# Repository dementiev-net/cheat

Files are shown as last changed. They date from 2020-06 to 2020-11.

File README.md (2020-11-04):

Электронная шпаргалка от AlexGyver
=====================

Это электронная шпаргалка, позволяющая незаметно списать тест. Авторский проект [AlexGyver](https://alexgyver.ru/gyvercheat/) разведенный на одной маленькой плате. Так же используется небольшой LiPo аккумулятор с возможностью зарядки. В остальном по функциональности ничем не отличается от версии на Arduino Nano.

| Сторона 1 | Сторона 2
|---|---
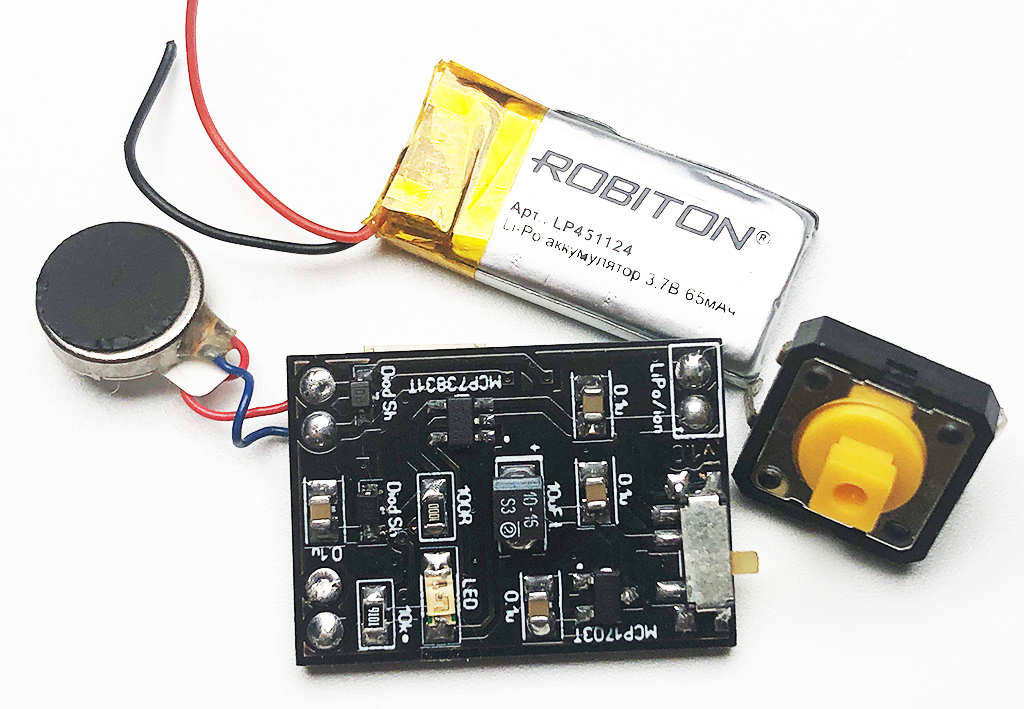
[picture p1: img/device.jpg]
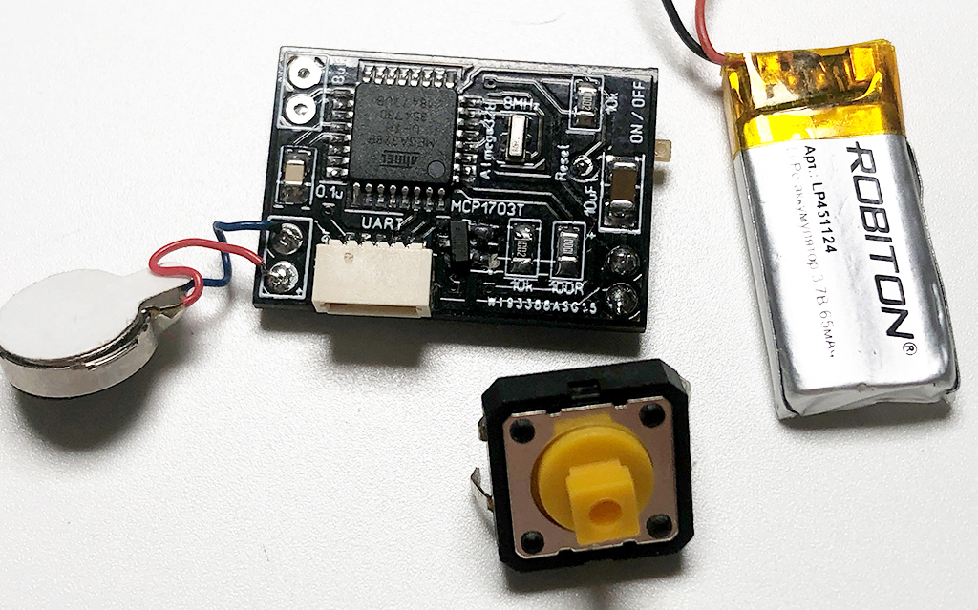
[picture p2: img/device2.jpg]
|  | 

Особенности:

*	Хранение ответов в EEPROM памяти микроконтроллера (до 1020 цифр);
*	Управление одной кнопкой;
*	Вывод ответов количеством вибраций;
*   Добавление билетов по UART;

## Инструкция по эксплуатации

Подключаем по UART к компьютеру и заносить билеты с ответами на них. Как это делается подробно рассказывает автор в своем [видео](https://www.youtube.com/watch?v=9YlfDXCbW8]).

Накликиваем нужный билет/вариант – получаем подтверждение в виде количества импульсов вибрации.

**Долгий клик** – выбор билета/варианта, подтверждение – одиночный короткий импульс вибрации. Пока билет не выбран долгим кликом, можно накликать другой номер!

**Клик** – вывод вибрацией ответа на следующий вопрос.

**Долгий клик** – возврат в меню, подтверждение – долгая вибрация. Долгая вибрация также будет при ошибках (нет такого билета, закончились вопросы в выбранном билете).

## Распиновка разъема

5-и контактный разъем JST-SH 1.0 мм. служит для подключение к USB через USB-UART конвертер а также зарядки аккумулятора. О зарядке информирует светодиод. Когда он погаснет - зарядка окончена.

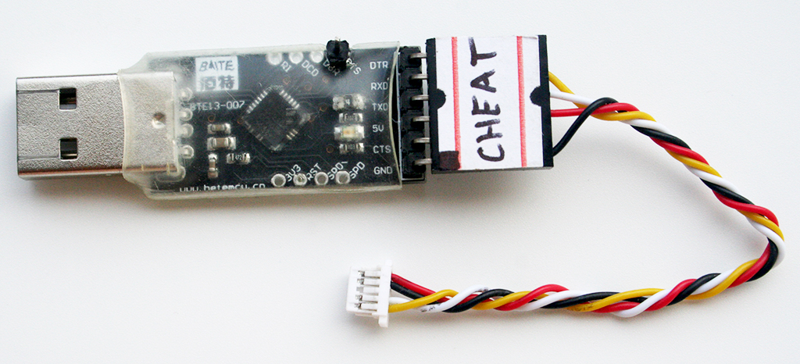
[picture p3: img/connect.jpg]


|  USB-UART конвертер | Разъем платы
|---|---
|1. DTR -|1. 5V - Красный провод
|2. RX - Желтый провод|2. GND - Черный провод
|3. TX - Белый провод|3. -
|4. 5V - Красный провод (нужен для зарядки аккумулятора)|4. RX - Белый провод
|5. CTS -|5. TX - Желтый провод
|6. GND - Черный провод (нужен для зарядки аккумулятора)|

## Схемы

Оригинальная схема автора. Используется Arduino Nano и плата контроллера заряда аккумулятора TP4056.

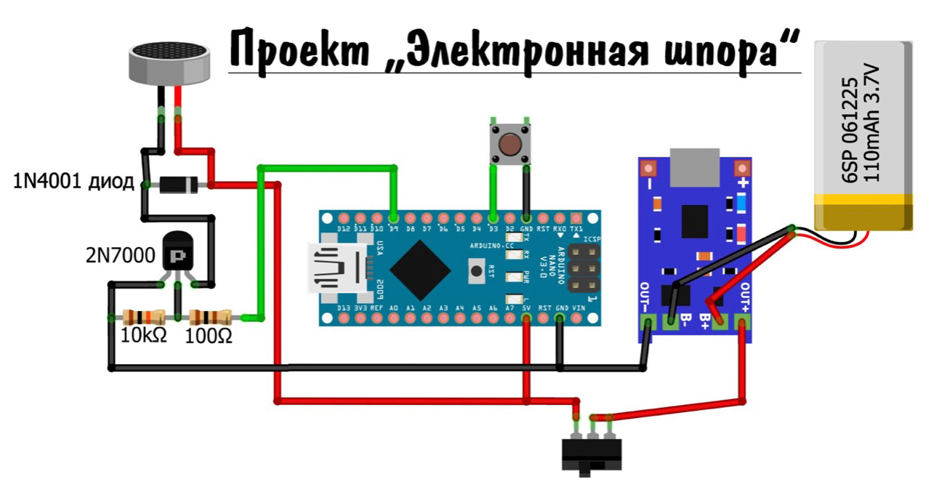
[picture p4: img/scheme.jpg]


В схему добавлено:

|MCP73831T-2ACI/OT<br>Контроллер заряда батарей Li-Ion/Li-Pol 15mA to 500mA 4.2V [SOT-23-5]| MCP1703T-3302E/CB<br>Регулятор напряжения линейный, 200MA 3.3V [SOT-23A]
|---|---
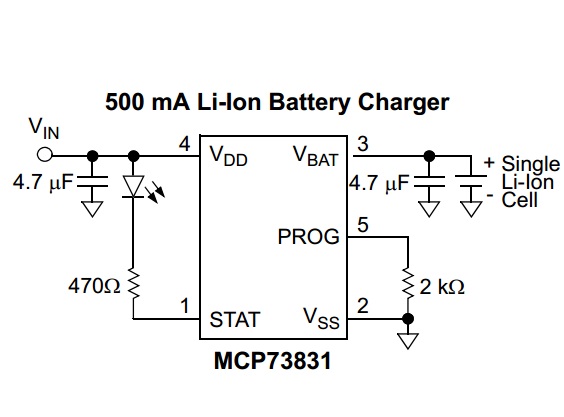
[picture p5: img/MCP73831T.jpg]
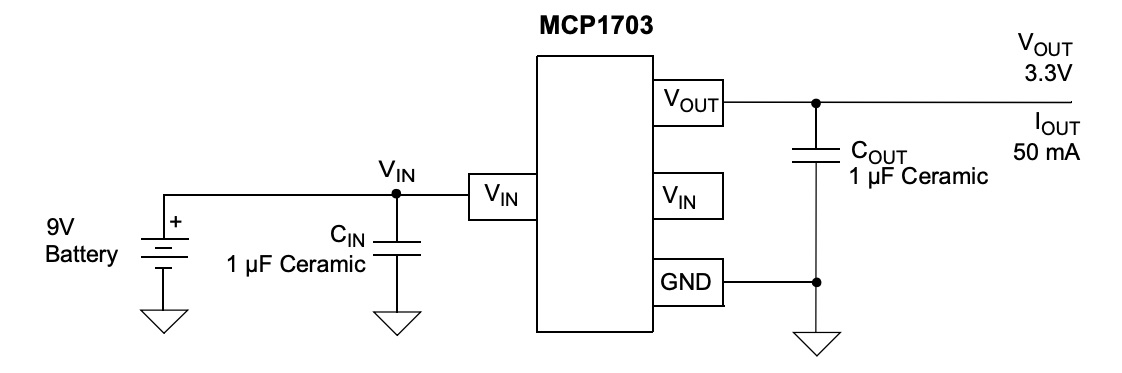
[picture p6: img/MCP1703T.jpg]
|  | 

## Плата

Делалась как можно компактнее, но пригодная к повторению.

| Верх | Низ
|---|---
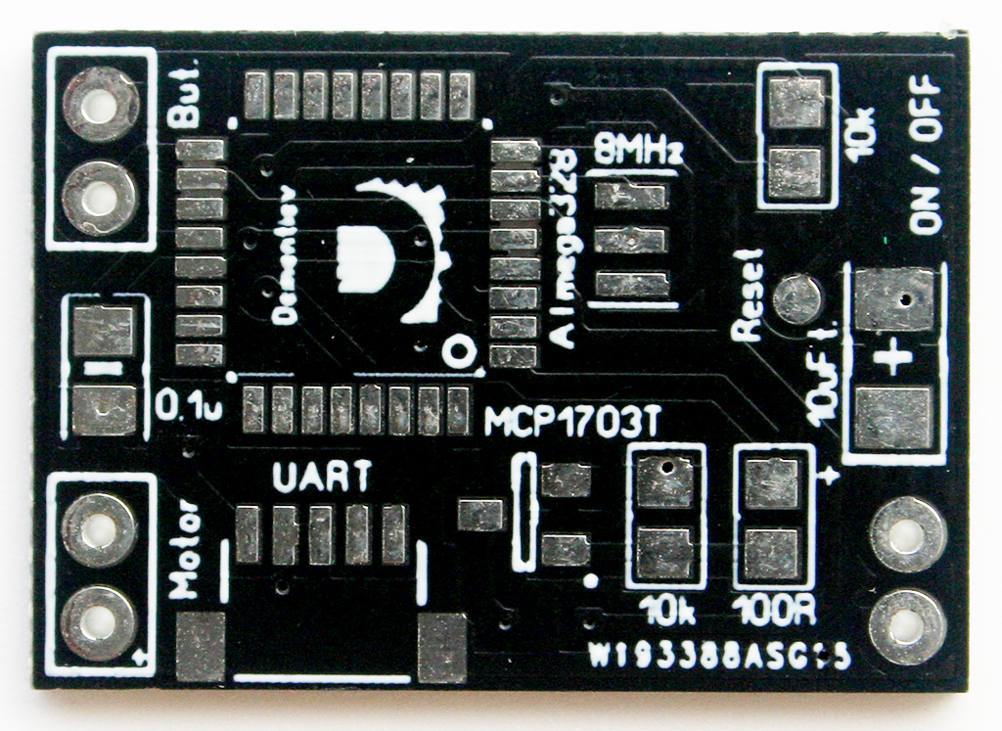
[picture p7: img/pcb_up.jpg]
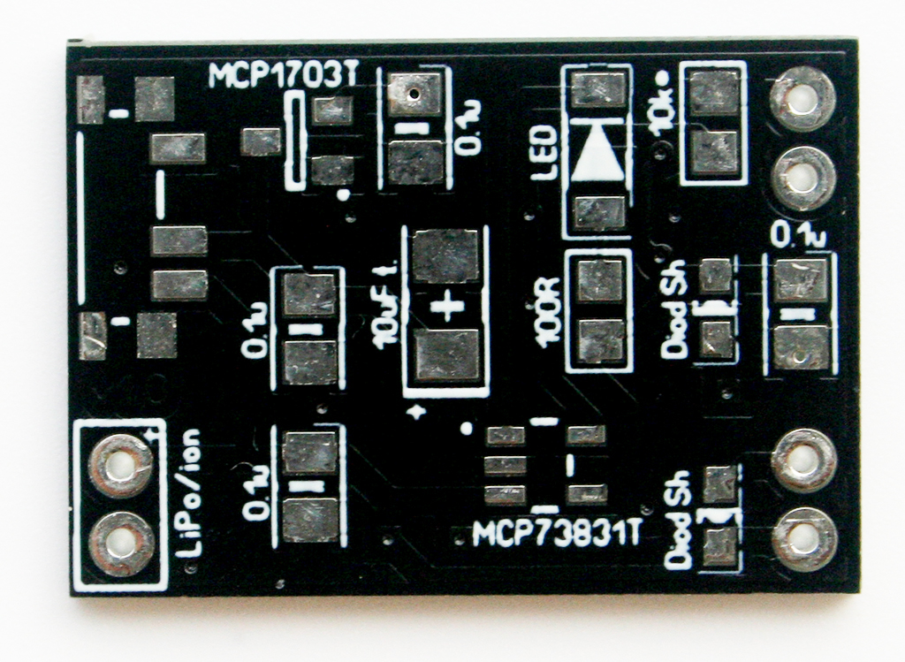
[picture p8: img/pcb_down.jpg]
|  | 

#### BOM:

|No|Name|Value|Layer|Comment
|---|---|---|---|---
|1|C1,C2|10u|Top,Bottom|Tantal
|2|C3,C4,C5,C6,C7|0.1u|Top,Bottom|0805
|3|D1,D2|BAT20|Bottom|SOD-323
|4|D3||Bottom|LED
|5|J1|SM05B-SRSS-TB|Top|
|6|J2|MK12C02|Bottom|
|7|Q1|8Mhz|Top|
|8|Q2|IRFML8244|Top|SOT-23A
|9|R1,R2,R3|10k|Top,Bottom|0805
|10|R4,R5|100R|Top,Bottom|0805
|11|U1|Atmega328|Top|TQFP-32
|12|U2|MCP73831T|Bottom|SOT-23-5
|13|U3|MCP1703T|Bottom|SOT-23A

## Корпус

Корпус распечатан на 3D принтере. Предназначен для удобной сборки в один небольшой корпус. Используется разъем JST PH 2.0 мм. 2-Pin для выноса кнопки на провод.

| Корпус | Сборка
|---|---
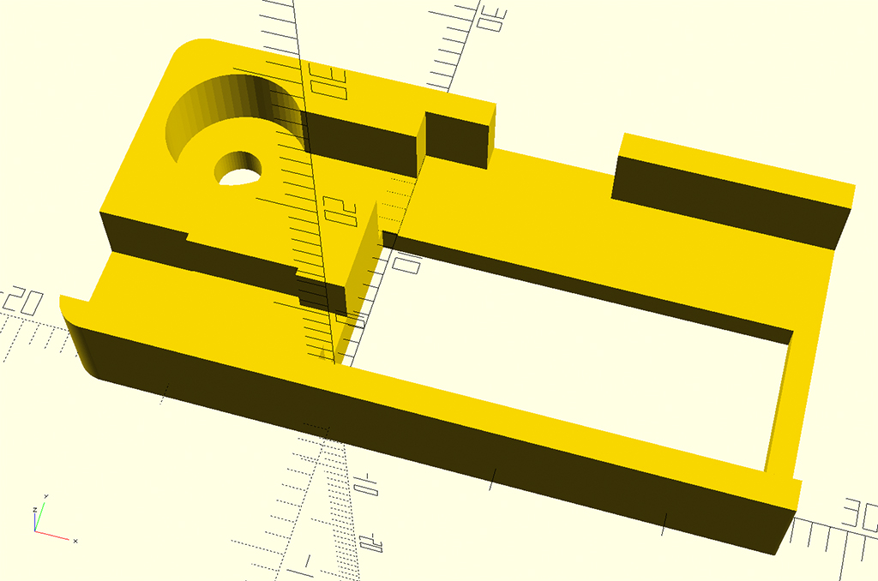
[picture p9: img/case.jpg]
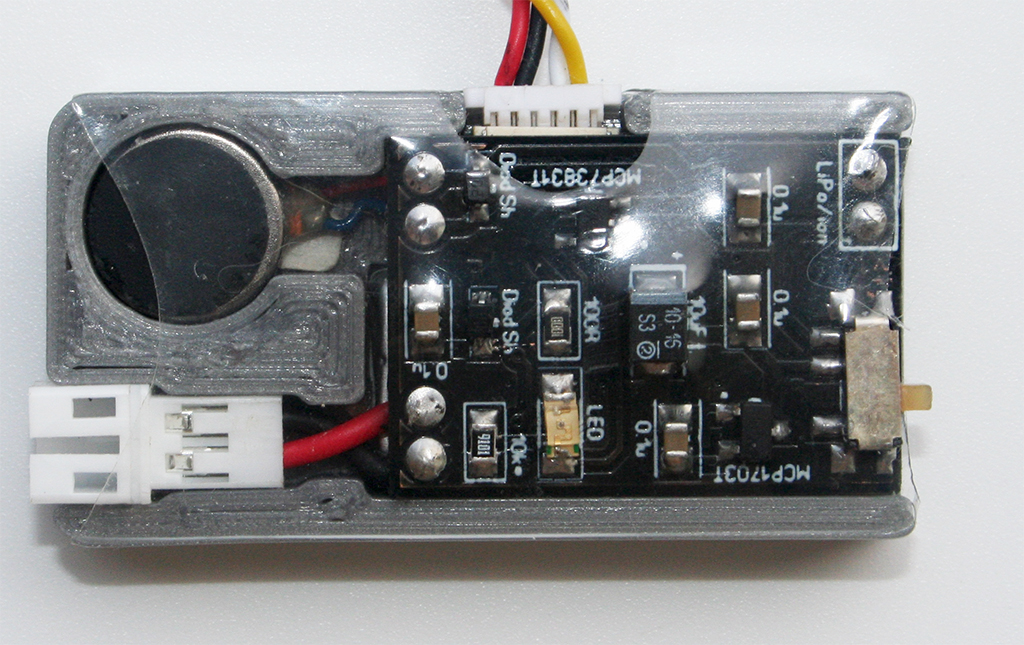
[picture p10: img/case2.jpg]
|  | 

## Прошивка

* Любым программатором загружается bootloader (HEX файл и фьюзы прилагаются). Самой простой вариант прошить через USB Arduino NANO и "сдуть" с нее чип.
* Впаивается чип на плату.
* Заливается INO файл из Arduino IDE (как Arduino NANO) с помощью USB-UART преобразователя (FTDI).

## Контакты

GitHub автора: [https://github.com/AlexGyver/GyverCheat](https://github.com/AlexGyver/GyverCheat)

Связаться со мной: info@dementiev.net

##### Лицензия: «Attribution-NonCommercial-ShareAlike»<br>(«Атрибуция — Некоммерческое использование — На тех же условиях») 4.0 Всемирная



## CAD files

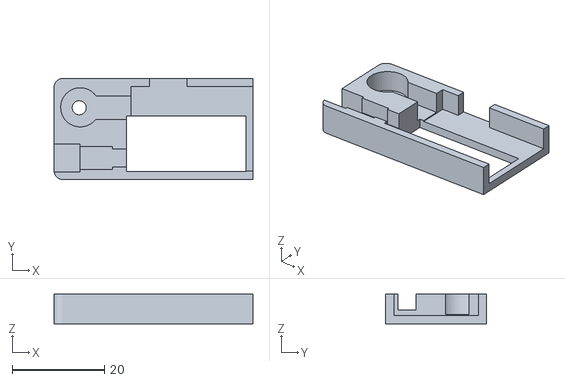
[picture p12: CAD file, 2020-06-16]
3d print/case 8mm motor.stl
43.2 x 22.0 x 6.50

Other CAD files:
3d print/case 10mm motor.stl

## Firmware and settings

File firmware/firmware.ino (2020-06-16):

/*
  Скетч к проекту "Электронная супер-шпора"
  Страница проекта (схемы, описания): https://alexgyver.ru/GyverCheat/
  Исходники на GitHub: https://github.com/AlexGyver/GyverCheat/
  Нравится, как написан код? Поддержи автора! https://alexgyver.ru/support_alex/
  Автор: AlexGyver Technologies, 2018
  https://AlexGyver.ru/

  Версия 1.1 - пофикшен критический баг!
*/

/*
   Накликиваем нужный билет/вариант - получаем подтверждение в виде количества импульсов вибрации
   Долгий клик - выбор билета/варианта, подтверждение - одиночный короткий импульс вибрации 
   Клик - вывод вибрацией ответа на следующий вопрос
   Долгий клик - возврат в меню, подтверждение - долгая вибрация
   Долгая вибрация также будет при ошибках (нет такого билета, закончились вопросы в выбранном билете)
*/

// ----------------- НАСТРОЙКИ -----------------
#define BUF_SIZE 1000	  // размер буфера (0-1021)
#define MODE 1          // 0 - карта памяти, 1 - EEPROM
#define MOTOR_SPEED 250 // скорость мотора (0-255)
#define BTN 13          // пин кнопки
#define MOTOR 3         // пин мотора

// настройки времени вибрации
#define PAUSE 500             // пауза между вибрациями, мс (когда выводит цифру)
#define LONG_VIBR 1500        // длинная вибрация, мс (при ошибках и любом выходе в корень)
#define ANSWER_VIBR 300       // длина импульса при выводе цифры, мс
#define MANY_ANSW_PAUSE 1000  // пауза между ответами, когда в вопросе их несколько, мс

// ----------------- ДЛЯ РАЗРАБОТЧИКОВ -----------------
#define SIZE_POS 1022     // позиция ячейки с размером буфера
#include "GyverButton.h"
GButton butt(BTN);

#if (MODE == 0)
#include <SPI.h>
#include <SD.h>
File myFile;
const char *filename;
#define logName "exam.txt"
#else
#include "EEPROMex.h"
#endif

char buf[BUF_SIZE];
uint16_t bufSize;
uint16_t bufPos;
uint16_t bufCounter;

void setup() {
  Serial.begin(9600);
  butt.setTimeout(800);
#if (MODE == 0)
  Serial.print(F("Initializing SD card..."));
  if (!SD.begin(10)) {
    Serial.println(F(" failed!"));
  }
  Serial.println(F(" done"));

  if (SD.exists(logName)) {
    Serial.print(logName); Serial.println(F(" found"));
  } else {
    Serial.print(logName); Serial.println(F(" not found"));
  }

  myFile = SD.open(logName, FILE_READ);

  int fileSize = myFile.size();
  bufPos = 0;
  bufCounter = 0;
  myFile.seek(0);
  for (int i = 0; i < fileSize; i++) {
    char sdBuf = (char)myFile.read();
    if (sdBuf > 38 && sdBuf < 122) {
      buf[bufCounter] = sdBuf;
      bufCounter++;
    }
  }
  bufSize = bufCounter;
#else
  if (EEPROM.read(SIZE_POS) != 255 && EEPROM.read(SIZE_POS + 1) != 255) {
    bufSize = EEPROM.readInt(SIZE_POS);
    for (int i = 0; i < bufSize; i++) {
      buf[i] = (char)EEPROM.readByte(i);
    }
    Serial.println(F("EEPROM read OK"));
  }
#endif
  Serial.println(F("System start"));
  pinMode(MOTOR, OUTPUT);
}

byte ticket = 1;
byte question = 0;
byte answer;
byte mode = 0;
uint16_t ticketPos;

char bufRead() {
#if (MODE == 0)
  char retChar = myFile.read();
#else
  char retChar = buf[bufPos];
#endif
  bufPos++;
  return retChar;
}

void loop() {
  if (Serial.available() > 0) {
    bufCounter = 0;
#if (MODE == 0)
    myFile.seek(0);   // в начало файла
#endif
    uint32_t timeoutTimer = millis();
    while (millis() - timeoutTimer < 500) {
      while (Serial.available() > 0) {
        timeoutTimer = millis();
        char serialBuf = Serial.read();
        if (serialBuf > 38 && serialBuf < 122) {
#if (MODE == 1)
          buf[bufCounter] = serialBuf;
          bufCounter++;
          if (bufCounter > BUF_SIZE) {
            Serial.println(F("Buffer overflow"));
            break;
          }
#else
          bufCounter++;
          myFile.print(serialBuf);
#endif
        }
      }
    }
    Serial.println(F("Serial read success"));
    bufSize = bufCounter;
#if (MODE == 1)
    for (int i = 0; i < bufSize; i++) {
      EEPROM.updateByte(i, (byte)buf[i]);
    }
    EEPROM.updateInt(SIZE_POS, bufSize);
    Serial.println(F("EEPROM write success"));
#else
    myFile.flush();
    Serial.println(F("SD write success"));
#endif
    for (int i = 0; i < bufSize; i++) {
      Serial.print(buf[i]);
    }
  }

  butt.tick();    // опрос кнопки

  if (butt.isHolded()) {
    if (mode == 0) {
      mode = 1;
      Serial.println(F("Ticket chosen"));
      bufPos = 0;
#if (MODE == 0)
      myFile.seek(0);   // в начало файла
#endif
      while (true) {
        if (bufRead() == 'B') {     // ищем префикс B
          char buf1 = bufRead();
          char buf2 = bufRead();
          byte tickNum;
          if (buf2 == ';') {        // если номер билета <10 (сразу встретили разделитель)
            tickNum = buf1 - '0';
            ticketPos = bufPos;
          } else {                  // если номер билета >10 (не встретили разделитель)
            tickNum = (buf1 - '0') * 10 + (buf2 - '0');
            bufPos++;
            ticketPos = bufPos;
          }
          if (tickNum == ticket) {
            Serial.println(F("Ticket found"));
            vibrate(1, ANSWER_VIBR);
            question = 0;
            break;
          }
        }
        if (bufPos >= bufSize) {
          Serial.println(F("Error: not found"));
          vibrate(1, LONG_VIBR);
          butt.getClicks(); // чистим буфер
          mode = 0;
          break;
        }
      }
    } else {
      mode = 0;
      Serial.println(F("Back to root"));
      vibrate(1, LONG_VIBR);
      butt.getClicks(); // чистим буфер
    }
  }

  if (butt.isClick() && mode == 1) {                // кликаем в режиме вывода ответов
    char bufChar;
    while (true) {
      if (bufPos >= bufSize) {                      // проверка на конец файла
        Serial.println(F("Error: end of file"));
        vibrate(1, LONG_VIBR);
        mode = 0;
        break;
      }
      bufChar = bufRead();
      if (bufChar == 'B') {                         // проверка на следующий билет
        mode = 0;
        Serial.println(F("The End. Back to root"));
        vibrate(1, LONG_VIBR);
        break;
      }
      if (buf[bufPos] == ',') {                     // если запятая
        char bufMany[10];                           // массив хранения нескольких ответов
        byte bufManyCounter = 0;                    // счетчик массива bufMany
        byte counter = 0;
        while (true) {
          bufMany[bufManyCounter] = buf[bufPos + counter - 1];  // пишем в массив
          counter++;                                            // счётчик
          if (buf[bufPos + counter - 1] == ',') {               // проверяем есть ли ещё запятая
            bufManyCounter++;       // в этом случае ++ количество ответов
            counter++;              // и счётчик
          } else break;
        }
        bufPos += (counter - 1);    // запоминаем позицию в файле с учётом ответа с запятыми
        question++;                 // ++ номер вопроса
        Serial.print("Question " + String(question) + ", answer: ");
        for (byte i = 0; i < bufManyCounter + 1; i++) {
          answer = bufMany[i] - '0';
          Serial.print(answer);
          vibrate(answer, ANSWER_VIBR);
          delay(MANY_ANSW_PAUSE);
          Serial.print(", ");
        }
        Serial.println();
        break;
      } else {                                      // если не запятая, а просто цифра
        answer = bufChar - '0';
        question++;
        Serial.println("Question " + String(question) + ", answer: " + String(answer));
        vibrate(answer, ANSWER_VIBR);
        break;
      }

    }
  }

  if (butt.hasClicks()) {
    if (mode == 0) {
      ticket = butt.getClicks();
      Serial.println("Ticket " + String(ticket));
      vibrate(ticket, ANSWER_VIBR);
    }
    /*  // выбор ответа кликами. Не работает одновременно с переключением
      else if (mode == 1) {
      question = butt.getClicks();
      myFile.seek(ticketPos - 1 + question * 3);
      answer = myFile.read() - '0';
      Serial.println("Fast question " + String(question) + ", answer: " + String(answer));
      }*/
  }
}

void vibrate(byte amount, int duration) {
  for (byte i = 0; i < amount; i++) {
    analogWrite(MOTOR, MOTOR_SPEED);
    delay(duration);
    analogWrite(MOTOR, 0);
    delay(PAUSE);
  }
}

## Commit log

2020-06-16 Некоммерческая лицензия
2020-06-16 Выгрузка проекта на Github
    [Cheat.DRL, Cheat_copper_bottom.gbr, Cheat_copper_top.gbr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]
2020-06-16 Файл описания README.md
2020-11-04 Поменял описание
2020-11-17 Повторная выгрузка на Github
    [Cheat.DRL, Cheat_copper_bottom.gbr, Cheat_copper_top.gbr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]
